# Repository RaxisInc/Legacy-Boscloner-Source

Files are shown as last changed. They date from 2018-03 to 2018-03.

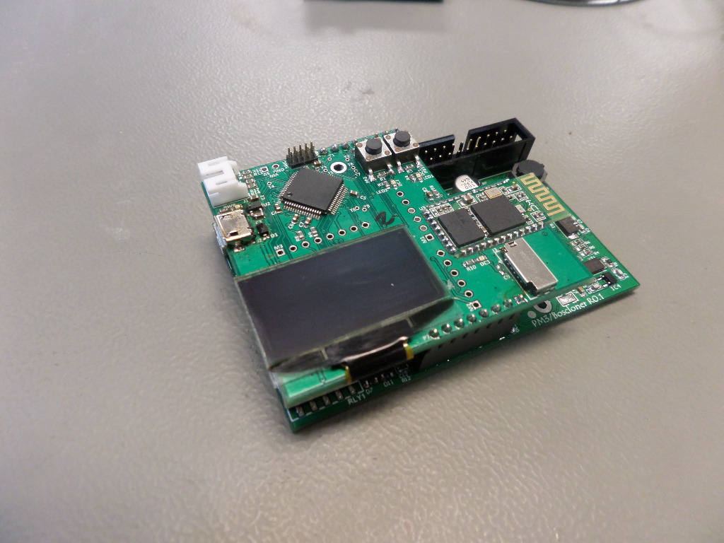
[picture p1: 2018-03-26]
Pics/SAM_0475.JPG

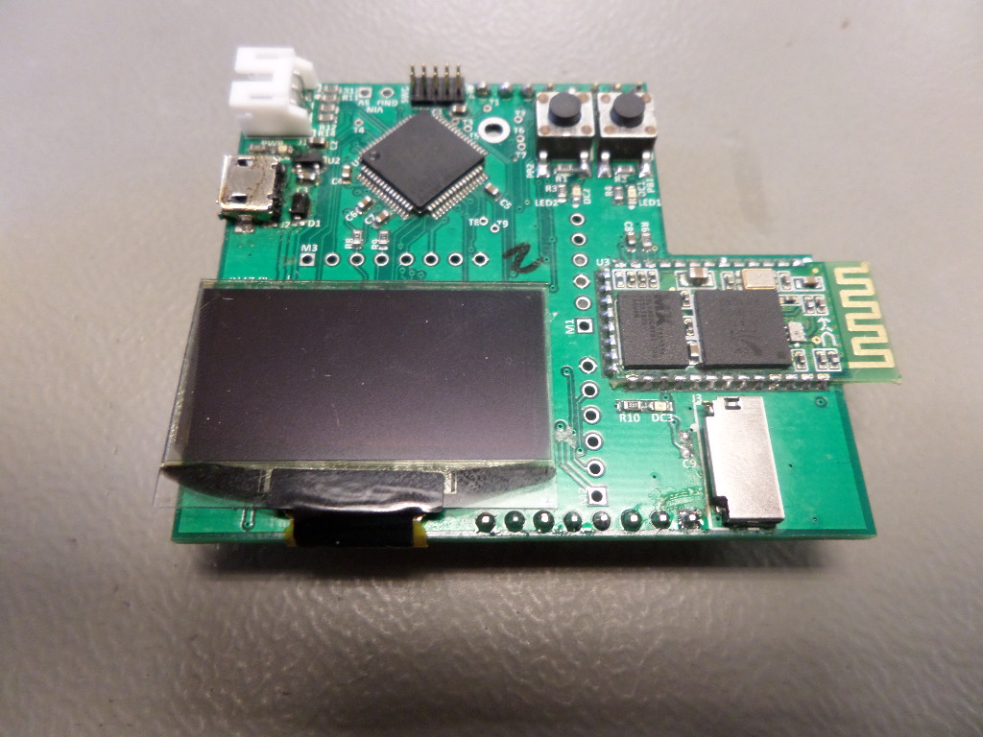
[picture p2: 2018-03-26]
Pics/SAM_0469.JPG

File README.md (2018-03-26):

# Boscloner-Source
The Official Location for All Boscloner Source Files for Hardware, Software, and Apps

In this repository, you'll find all the source, diagrams, BOMs, and more necessary to create your own Boscloner board and shield.

For the Boscloner iOS App Source, visit here:
https://github.com/Boscloner/Boscloner-iOS-App

For the Android App Source, visit here:
https://github.com/Boscloner/Boscloner-Android-App

For assembly, build instructions, and other supporting videos and documentation, visit here:
http://www.boscloner.com

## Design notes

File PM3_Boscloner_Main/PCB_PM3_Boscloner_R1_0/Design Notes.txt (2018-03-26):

Ra.0 errors

- ic9/10 need spaced further based upon replacement part.  Also need to extend pads.

- NCA is nowehow connected where the lcd cs should be.  connected MCU_cs to it!?  But
the correct cs line ps10 is connected to mcu_io3.

PA10 = LCD CS WHICH IS SETUP IN CODE ALREADY.  CAN USE FOR THE PERIPHERAL BOARD.

* routing the SPI pins to shield and secondary processor.

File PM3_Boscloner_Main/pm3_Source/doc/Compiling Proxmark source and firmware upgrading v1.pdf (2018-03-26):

COMPILING PROXMARK SOURCE AND FIRMWARE UPGRADING

Version 1

INTENDED AUDIENCE

The Proxmark III is intended for users that are either competent hardware or software developers (preferably both). Users that do not understand the basic principles behind RFID may have difficulty using the device.

The Proxmark III is a RFID development tool. Typically, an "out of the box" proxmark3 with the latest firmware can run acquisitions in LF and HF mode, output traces, decode a number of different RFID credentials and do some operations in ISO 15693 and ISO 14443 a and b modes. If you really want to get the most out of this device, you will need to start enhancing the firmware yourself to suit your needs.

BEFORE YOU START

This document has been created assuming that you have read the relevant getting started guide and configured your development environment accordingly.

For Windows users – Everything in this document is done from the Minimalist GNU terminal window. Start by running “runme.bat”.

COMPILING PROXMARK SOURCE

Compiling the Proxmark source should be straight forward. To build the project type “make clean && make all”. The clean and build process will only take a few seconds before returning you back to the prompt. If the project was built successfully you should be able to run “./client/proxmark3.exe”. Building the Proxmark project will also produce 3 elf firmware files:

The bootrom image - “./bootrom/obj/bootrom.elf”.

The FPGA image - “./armsrc/obj/fpgaimage.elf”.

The OS image - “./armsrc/obj/osimage.elf”.

If any mention of an error occurs we suggest you request help from the Proxmark community by pasting a copy of the terminal output from the build process and a description of what you were trying to achieve.

FLASHING FIRMWARE

Proxmark firmware is comprised of three logical sections: bootrom, fpga and operating system. The bootrom is a relatively small bit of code that performs some basic hardware initialization, supports reflashing the device over USB and knows how to transfer execution to the operating system. Due to the limited number of features exposed by the bootrom, it is not frequently updated and so you should only rarely need to update it when there is a compatibility conflict.

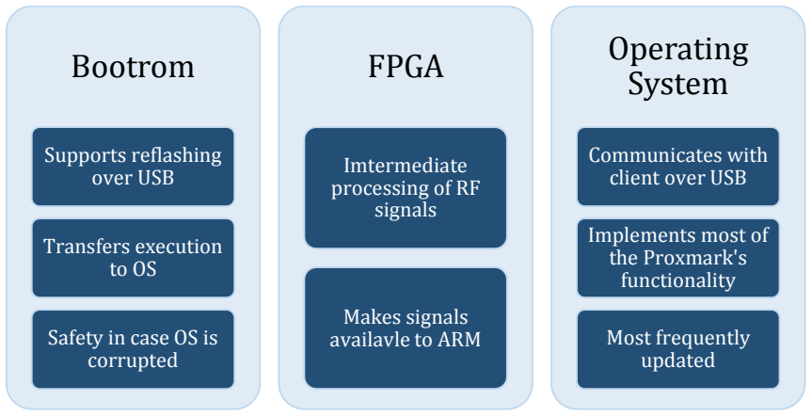
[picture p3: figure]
Bootrom; Supports reflashing over USB; Transfers execution to OS; Safety in case OS is corrupted; FPGA; Imtermediate processing of RF signals; Makes signals availavle to ARM; Operating System; Communicates with client over USB; Implements most of the Proxmark's functionality; Most frequently updated

The FPGA code processes analogue signals coming from the antennas and makes those signals available to the ARM. Like the bootrom code, the FPGA code is not frequently updated. Presently, the operating system is the most frequently updated portion of Proxmark code. It is responsible for receiving and executing most of the commands advertised in the client user interface. Upgrading the bootrom of your Proxmark can brick the device. Please exercise caution when upgrading the bootloader. If the bootloader is corrupted, the only way to restore your Proxmark to working order will be through the use of a JTAG programmer.

FLASHING PROCEDURE

Ensure that you have read the prior section before proceeding. In order to upgrade to the latest version of firmware, you will need to first upgrade the Proxmark’s bootloader.

The steps below will upgrade the Proxmark bootloader to the version you checked out previously using the procedure from the getting started guide.

1. Optional – Update your working copy to the latest revision. (Refer to the getting started documentation).
2. If you have not already done so, open up a terminal and go to the “pm3/client“ directory.
3. Press and hold the button on the Proxmark while connecting it to your computer. Continue to hold the button until the yellow and red LEDs stay lit.
4. Upgrade the Proxmark bootrom by executing the following command:

sudo ./flasher -b ../bootrom/obj/bootrom.elf

At this point the bootrom has been updated and the Proxmark is now in a position to have its OS upgraded. The following steps will upgrade the Proxmark Operating System and FPGA code to your checked revision.

1. Ensure that the Proxmark is not connected to the PC.
2. Hold down the Proxmark’s button and connect it to the PC. After the yellow and red LEDs are lit, execute the command below:

sudo ./flasher ../armsrc/obj/fpgaimage.elf

1. If the previous step is successful, disconnect the Proxmark.
2. While holding the button, connect the Proxmark to the PC and wait for the yellow and red LEDs to stay lit. Execute the command below:

sudo ./flasher ../armsrc/obj/osimage.elf

3. Disconnect the Proxmark from the PC and then reconnect it.
4. Launch the client software by executing “./proxmark3.exe”. The client should successfully connect to the Proxmark. You should see something like this:

Connected units:

1. SN: ChangeMe [bus-0/\\.\libusb0-0001--0x9ac4-0x4b8f]

proxmark3>

JTAG RECOVERY PROCEDURE

If for whatever reason the USB upgrade procedure (section above) failed and the Proxmark will no longer boot, you will need to load the bootrom on to the Proxmark using the JTAG interface. This procedure assumes that you have a Segger J-LINK for the recovery process and J-Flash ARM installed on a PC running Windows 7.

1. Plug the Proxmark and the Segger J-LINK in to the computer.
2. Attach the J-LINK to the Proxmark JTAG port.
3. Open J-Flash ARM.
4. Create a new project by selecting File > New project.
5. Change the project settings by going to Options > Project settings…

– or –

Alt | + | F7 .
6. Click on the Target Interface tab.
7. Change the JTAG speed before init to 200 kHz.
8. Click on the CPU tab.
9. Select the Device radio button and select Atmel AT91SAM7S256 from the drop down list.
10. Change the Clock speed to Auto detection.
11. Apply and OK the changes.
12. Test connectivity to the Proxmark by selecting Target > Connect.

13. Disconnect from the Proxmark by selecting Target > Disconnect.
14. Open the data file by selecting File > Open data file…

– or –

Ctrl | + | O .
15. Open the file “bootrom.s19” which should be located in the “pm3\bootrom\obj” folder. If it is not there, you will need to re-build the project.
16. Program the Proxmark and verify the process by selecting Target > Program & Verify

– or –

F6 .

17. You should expect to see an error saying that the program does not fit into the selected flash sectors. Select Yes to relocate and continue.
18. Disconnect from the Proxmark by selecting Target > Disconnect.
19. Exit J-Flash ARM.
20. Remove the J-LINK from the Proxmark.
21. Wait a little while and the Proxmark should automatically re-start. You can always un-plug and re-plug the Proxmark if you wish. You can then attempt to re-connect to the Proxmark using the client software.

Thanks to the proxmark3.com guys for letting me use some of their original content!

USEFUL LINKS

The Proxmark forum | http://proxmark.org/forum/index.php
Proxmark III online store | http://proxmark3.com/
Proxmark project downloads | http://code.google.com/p/proxmark3/downloads/list
The Proxmark project | http://code.google.com/p/proxmark3/
The Proxmark wiki | http://code.google.com/p/proxmark3/wiki/HomePage?tm=6
Proxmark repository | http://proxmark3.googlecode.com/svn/trunk/
Document corrections or comments | http://proxmark.org/forum/viewforum.php?id=27

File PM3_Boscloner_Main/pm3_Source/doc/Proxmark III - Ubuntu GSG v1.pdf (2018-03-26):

GETTING STARTED GUIDE FOR UBUNTU (GNOME) USERS

Version 1

INTENDED AUDIENCE

The Proxmark III is intended for users that are either competent hardware or software developers (preferably both). Users that do not understand the basic principles behind RFID may have difficulty using the device.

The Proxmark III is a RFID development tool. Typically, an "out of the box" proxmark3 with the latest firmware can run acquisitions in LF and HF mode, output traces, decode a number of different RFID credentials and do some operations in ISO 15693 and ISO 14443 a and b modes. If you really want to get the most out of this device, you will need to start enhancing the firmware yourself to suit your needs.

INTRODUCTION

The proxmark3 is a powerful general purpose RFID tool, the size of a deck of cards, designed to snoop, listen and emulate everything from Low Frequency (125 kHz) to High Frequency (13.56 MHz) tags.

This device can do almost anything involving almost any kind of low (125 kHz) or high (13.56 MHz) frequency RFID tag. It can act as a reader. It can eavesdrop on a transaction between another reader and a tag. It can analyse the signal received over the air more closely, for example to perform an attack in which we derive information from the tag’s instantaneous power consumption. It can pretend to be a tag itself. It is also capable of some less obviously useful operations that might come in handy for development work.

HISTORY

“The Proxmark III is a device developed by Jonathan Westhues that enables sniffing, reading and cloning of RFID (Radio Frequency Identification) tags. For my master thesis I wanted to look at the communication of Mifare Classic cards. Mifare Classic is used in many applications and is the most popular contactless card around. It is used in e-ticketing, public transport and access control. The higher-level protocol is kept secret by the manufacturer (NXP). I made an implementation of the ISO14443 type A standard for the Proxmark since Mifare is based on this communication standard.

After a lot of debugging and many noisy traces the Proxmark was ready for some real analysis. I focused on the Mifare Classic card and was happy to let the communication between card and reader appear on my screen. I could see the anticollision phase where the reader selects the card to communicate with. This was followed by an authentication and after that all communication was encrypted. The findings of this research are published on arxiv.org as A Practical Attack on the Mifare Classic

In December 2007 I saw the presentation of Karsten Nohl and Henryk Plotz where they showed how they reverse engineered the Mifare Classic chip. I was working on the same subject in Nijmegen. The Mifare system relied on security by obscurity and now the secrets are revealed there is no card-level security left. A video on YouTube shows a demo that we gave on March 12th. It shows how we access a building with a cloned card.

We will not release the software used in the MIFARE Classic attacks.

Gerhard de Koning Gans, Roel Verdult”

HARDWARE OVERVIEW

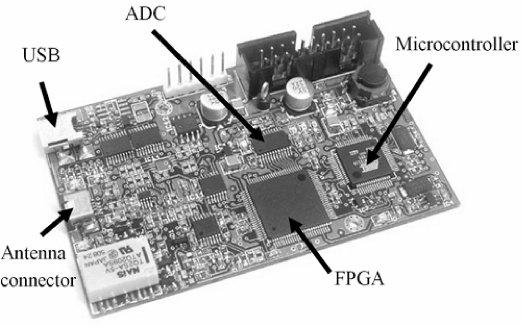
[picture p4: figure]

ADC (ANALOG TO DIGITAL CONVERTER)

The analogue signal that comes from the antenna circuit is fed into an 8-bit Analogue to Digital Converter (ADC). This delivers 8 output bits in parallel which represent the current voltage retrieved from the field.

FIELD PROGRAMMABLE GATE ARRAY

The 8 output pins from the ADC are connected to 8 pins of the Field Programmable Gate Array (FPGA). An FPGA has a great advantage over a normal microcontroller in the sense that it emulates hardware. A hardware description can be compiled and flashed into an FPGA.

Because basic arithmetic functions can be performed fast and in parallel by an FPGA it is faster than an implementation on a normal microcontroller. Only a real hardware implementation would be faster but this lacks the flexibility of an FPGA.

The FPGA can therefore be seen as dynamic hardware. It is possible to make a hardware design and flash it into the memory of the FPGA. This gives some major advantages:

"Hardware" errors can be corrected; the FPGA can be flashed with a new hardware design. Although not as fast as a real hardware implementation, an FPGA is faster than its equivalent on a microprocessor. That is, it is specialized for one job.

The FPGA has two main tasks. The first task is to demodulate the signal received from the ADC and relay this as a digital encoded signal to the ARM. Depending on the task this might be the demodulation of a

100% Amplitude Shift Keying (ASK) signal from the reader or the load modulation of a card. The encoding schemes used to communicate the signal to the ARM are Modified Miller for the reader and Manchester encoding for the card signal.

The second task is to modulate an encoded signal that is received from the ARM into the field of the antenna. This can be both the encoding of reader messages or card messages. For reader messages the FPGA generates an electromagnetic field on power hi and drops the amplitude for short periods.

MICROCONTROLLER

The microcontroller is responsible for the protocol management. It receives the digital encoded signals from the FPGA and decodes them. The decoded signals can just be copied to a buffer in the EEPROM memory. Additionally, an answer to the received message can be send by encoding a reply and communicating this to the FPGA.

The microcontroller (ARM) implements the transport layer. First it decodes the samples received from the FPGA. These samples are stored in a Direct Memory Access (DMA) buffer. The samples are binary sequences that represent whether the signal was high or low. The software on the ARM tries to decode these samples. When the Proxmark is in sniffing mode this is done for both the Manchester and Modified Miller at the same time. Whenever one of the decoding procedures returns a valid message, this message is stored in another buffer (BigBuf) and both decoding procedures are set to an un-synced state. The BigBuf is limited to the available memory on the ARM. The current firmware has 2 KB of memory reserved for traces (Besides the traces the buffer also stores some temporary data that is needed in the processing). When the BigBuf buffer is full the function normally returns. A new function call from the client is needed to download the BigBuf contents to the computer. The BigBuf is especially useful for protocol investigation. Every single message is stored in this buffer. When a card is emulated or when the Proxmark is used as a reader the BigBuf can be used to store status messages or protocol exceptions.

USB

The USB interface interconnects the Proxmark with an external power supply and / or a computer for advanced functionality.

ANTENNA CONNECTOR

The antenna connector is a Hirose Electric low profile, surface mount, right-angle 4 pin connector. This connector allows for the simultaneous connection of a low and high frequency antenna.

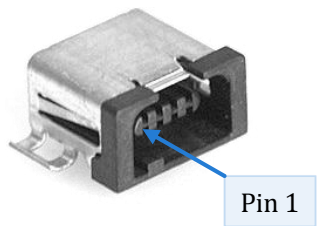
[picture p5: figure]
Pin 1

The low frequency antenna (125/134 kHz) connects to Pin 1 (TP5) and Pin 2 (TP2). The high frequency antenna (13.56MHz) connects to Pin 3 (TP4) and Pin 4 (TP3).

GETTING STARTED

It is assumed that the reader of this document is running Ubuntu 11.10. This document is intended as a guide only. Group policies and custom configurations are outside the scope of this document.

A high and low frequency antenna will be required when testing the Proxmark. The antenna construction is outside the scope of this document. It is assumed that the antennas have been assembled and tested prior to reading “Testing the Proxmark”.

REQUIREMENTS

A computer running Ubuntu 11.10 with an available USB port.
- This guide will most likely work with:
- Ubuntu 11.04, 10.10 and 10.04.
- BackTrack 5 R1 and 4 R2.
A USB Mini-B lead.
A Proxmark III.
HF and / or LF antenna for the Proxmark.

A technical understanding of the Proxmark III is not required for the installation process.

DEVELOPMENT ENVIRONMENT INSTALLATION

1. Open a terminal: | CTRL | + | ALT | + | T | .
2. Download (and install) TortoiseSVN, p7zip, and components essential to build the Proxmark from
soruce: “sudo apt-get install subversion p7zip build-essential libreadline5

libreadline-dev libusb-0.1-4 libusb-dev libqt4-dev perl pkg-config wget”.
3. Check out the latest revision of the Proxmark project: “svn checkout

http://proxmark3.googlecode.com/svn/trunk pm3”.
4. Get devkitARM release 32 (4.5.1) from SourceForge: http://sourceforge.net/projects/devkitpro/files/devkitARM/previous/devkitARM_r32-i686-linux.tar.bz2/download (http://sourceforge.net/projects/devkitpro/files/devkitARM/previous/devkitARM_r32-i686-linux.tar.bz2/download)
5. Extract the contents of the .tar.bz2: “tar jxvf devkitARM_r32-i686-linux.tar.bz2”.
6. Create a directory for the arm dev kit: “sudo mkdir /opt/devkitpro/”.
7. Move the ARM developer kit to the newly created directory: “sudo mv devkitARM

/opt/devkitpro/”.
8. Add the appropriate environment variable: “export

PATH=${PATH}:/opt/devkitpro/devkitARM/bin/”.
9. Add the environment variable to your profile: “echo

'PATH=${PATH}:/opt/devkitpro/devkitARM/bin/' >> ~/.bashrc”.

PROXMARK DRIVER INSTALLATION

No drivers are required to use the Proxmark within Linux. You will however need to run the client as root.

TESTING THE PROXMARK

You are now at the stage where you should be able to communicate with your Proxmark.

1. Go in to your Proxmark project folder and run the Proxmark software – “sudo

./client/proxmark3.exe”.
1.1. You should see something like this:

Connected units:

1. SN: ChangeMe [bus-0/\\.\libusb0-0001--0x9ac4-0x4b8f]

proxmark3>

2. Next, check what firmware you are running – “hw version”.
2.1. You should see something like this:

#db# Prox/RFID mark3 RFID instrument

#db# bootrom: svn 486-suspect 2011-07-18 12:48:52

#db# os: svn 486-suspect 2011-07-18 12:48:57

#db# FPGA image built on 2009/12/ 8 at 8: 3:54

3. Connect your antenna(s) to the Proxmark and type in “hw tune”.
3.1. You should see something like this:

#db# Measuring antenna characteristics, please wait.

# LF antenna: 33.17 V @ | 125.00 kHz

# LF antenna: 41.89 V @ | 134.00 kHz

# LF optimal: 41.76 V @ | 127.66 kHz

# HF antenna: | 7.28 V @ | 13.56 MHz

4. Type “quit” to exit out of the program.

NOTES

There are many commands available within the Proxmark client. Type “help” to list the commands available to you. You get a list of following subcommands by typing in the command you’re interested followed by help (Eg. “hf help”). For detailed help please read the Proxmark User Manual.

Command shortcutting is permitted. For instance typing “hf mf re” will achieve the same results as typing “hf mf restore1k” because it is the only “hf mf” command available that begins with “re”.

You might have noticed when you executed the command “hw version” there was a “-unclean” or “-suspect” in the “bootrom” or “os” version information. This information indicates that the code may have changes in the local code versus the subversion revision.

A clean build is a build that has no local changes versus the subversion revision.
Unclean builds have local changes versus the subversion revision.
Suspect builds cannot be compared against the subversion revision.

NEXT STEPS

From here on in the rest is up to you. You might want to confirm that the firmware you’re running is the latest. In addition to this you might want to begin reading through the Proxmark source code and making changes of your own.

We suggest you read the following documentation:

Compiling Proxmark source and firmware upgrading Proxmark User Manual
Antenna Construction Guide

THE FORUM

We hope you thoroughly enjoy using the Proxmark and encourage you to join the forum and introduce yourself - http://proxmark.org/forum/index.php. There are a number of active members willing to assist newcomers. Please note the forum is not a help desk for inexperienced developers. Poor English,

USEFUL LINKS

The Proxmark forum | http://proxmark.org/forum/index.php
Proxmark project downloads | http://code.google.com/p/proxmark3/downloads/list
The Proxmark project | http://code.google.com/p/proxmark3/
The Proxmark wiki | http://code.google.com/p/proxmark3/wiki/HomePage?tm=6
Proxmark repository | http://proxmark3.googlecode.com/svn/trunk/
7-Zip | http://www.7-zip.org
Tortoise SVN | http://tortoisesvn.net
Document corrections or comments | http://proxmark.org/forum/viewforum.php?id=27

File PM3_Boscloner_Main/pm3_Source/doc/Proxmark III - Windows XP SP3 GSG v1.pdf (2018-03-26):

# PROXMARK III

GETTING STARTED GUIDE FOR WINDOWS XP USERS

Version 1

INTENDED AUDIENCE

The Proxmark III is intended for users that are either competent hardware or software developers (preferably both). Users that do not understand the basic principles behind RFID may have difficulty using the device.

The Proxmark III is a RFID development tool. Typically, an "out of the box" proxmark3 with the latest firmware can run acquisitions in LF and HF mode, output traces, decode a number of different RFID credentials and do some operations in ISO 15693 and ISO 14443 a and b modes. If you really want to get the most out of this device, you will need to start enhancing the firmware yourself to suit your needs.

INTRODUCTION

The proxmark3 is a powerful general purpose RFID tool, the size of a deck of cards, designed to snoop, listen and emulate everything from Low Frequency (125 kHz) to High Frequency (13.56 MHz) tags.

This device can do almost anything involving almost any kind of low (125 kHz) or high (13.56 MHz) frequency RFID tag. It can act as a reader. It can eavesdrop on a transaction between another reader and a tag. It can analyse the signal received over the air more closely, for example to perform an attack in which we derive information from the tag’s instantaneous power consumption. It can pretend to be a tag itself. It is also capable of some less obviously useful operations that might come in handy for development work.

HISTORY

“The Proxmark III is a device developed by Jonathan Westhues that enables sniffing, reading and cloning of RFID (Radio Frequency Identification) tags. For my master thesis I wanted to look at the communication of Mifare Classic cards. Mifare Classic is used in many applications and is the most popular contactless card around. It is used in e-ticketing, public transport and access control. The higher-level protocol is kept secret by the manufacturer (NXP). I made an implementation of the ISO14443 type A standard for the Proxmark since Mifare is based on this communication standard.

After a lot of debugging and many noisy traces the Proxmark was ready for some real analysis. I focused on the Mifare Classic card and was happy to let the communication between card and reader appear on my screen. I could see the anticollision phase where the reader selects the card to communicate with. This was followed by an authentication and after that all communication was encrypted. The findings of this research are published on arxiv.org as A Practical Attack on the Mifare Classic

In December 2007 I saw the presentation of Karsten Nohl and Henryk Plotz where they showed how they reverse engineered the Mifare Classic chip. I was working on the same subject in Nijmegen. The Mifare system relied on security by obscurity and now the secrets are revealed there is no card-level security left. A video on YouTube shows a demo that we gave on March 12th. It shows how we access a building with a cloned card.

We will not release the software used in the MIFARE Classic attacks.

Gerhard de Koning Gans, Roel Verdult”

HARDWARE OVERVIEW

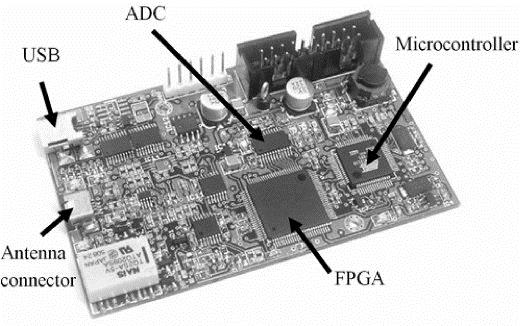
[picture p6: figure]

ADC (ANALOG TO DIGITAL CONVERTER)

The analogue signal that comes from the antenna circuit is fed into an 8-bit Analogue to Digital Converter (ADC). This delivers 8 output bits in parallel which represent the current voltage retrieved from the field.

FIELD PROGRAMMABLE GATE ARRAY

The 8 output pins from the ADC are connected to 8 pins of the Field Programmable Gate Array (FPGA). An FPGA has a great advantage over a normal microcontroller in the sense that it emulates hardware. A hardware description can be compiled and flashed into an FPGA.

Because basic arithmetic functions can be performed fast and in parallel by an FPGA it is faster than an implementation on a normal microcontroller. Only a real hardware implementation would be faster but this lacks the flexibility of an FPGA.

The FPGA can therefore be seen as dynamic hardware. It is possible to make a hardware design and flash it into the memory of the FPGA. This gives some major advantages:

- "Hardware" errors can be corrected; the FPGA can be flashed with a new hardware design.
- Although not as fast as a real hardware implementation, an FPGA is faster than its equivalent on a microprocessor. That is, it is specialized for one job.

The FPGA has two main tasks. The first task is to demodulate the signal received from the ADC and relay this as a digital encoded signal to the ARM. Depending on the task this might be the demodulation of a

100% Amplitude Shift Keying (ASK) signal from the reader or the load modulation of a card. The encoding schemes used to communicate the signal to the ARM are Modified Miller for the reader and Manchester encoding for the card signal.

The second task is to modulate an encoded signal that is received from the ARM into the field of the antenna. This can be both the encoding of reader messages or card messages. For reader messages the FPGA generates an electromagnetic field on power hi and drops the amplitude for short periods.

MICROCONTROLLER

The microcontroller is responsible for the protocol management. It receives the digital encoded signals from the FPGA and decodes them. The decoded signals can just be copied to a buffer in the EEPROM memory. Additionally, an answer to the received message can be send by encoding a reply and communicating this to the FPGA.

The microcontroller (ARM) implements the transport layer. First it decodes the samples received from the FPGA. These samples are stored in a Direct Memory Access (DMA) buffer. The samples are binary sequences that represent whether the signal was high or low. The software on the ARM tries to decode these samples. When the Proxmark is in sniffing mode this is done for both the Manchester and Modified Miller at the same time. Whenever one of the decoding procedures returns a valid message, this message is stored in another buffer (BigBuf) and both decoding procedures are set to an un-synced state. The BigBuf is limited to the available memory on the ARM. The current firmware has 2 KB of memory reserved for traces (Besides the traces the buffer also stores some temporary data that is needed in the processing). When the BigBuf buffer is full the function normally returns. A new function call from the client is needed to download the BigBuf contents to the computer. The BigBuf is especially useful for protocol investigation. Every single message is stored in this buffer. When a card is emulated or when the Proxmark is used as a reader the BigBuf can be used to store status messages or protocol exceptions.

USB

The USB interface interconnects the Proxmark with an external power supply and / or a computer for advanced functionality.

ANTENNA CONNECTOR

The antenna connector is a Hirose Electric low profile, surface mount, right-angle 4 pin connector. This connector allows for the simultaneous connection of a low and high frequency antenna.

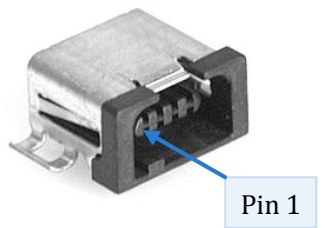
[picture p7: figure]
Pin 1

- The low frequency antenna (125/134 kHz) connects to Pin 1 (TP5) and Pin 2 (TP2).
- The high frequency antenna (13.56MHz) connects to Pin 3 (TP4) and Pin 4 (TP3).

GETTING STARTED

It is assumed that the reader of this document is the local administrator of a machine running Windows XP Professional SP3. This document is intended as a guide only. Group policies and custom configurations are outside the scope of this document.

A high and low frequency antenna will be required when testing the Proxmark. The antenna construction is outside the scope of this document. It is assumed that the antennas have been assembled and tested prior to reading “Testing the Proxmark”.

REQUIREMENTS

- A computer running Windows XP Professional SP3 with an available USB port.
- A USB Mini-B lead.
- A Proxmark III.
- HF and / or LF antenna for the Proxmark.

A technical understanding of the Proxmark III is not required for the installation process.

DEVELOPMENT ENVIRONMENT INSTALLATION

1. Download (and install) 7-ZIP from here: http://www.7-zip.org/download.html
2. Download (and install) TortoiseSVN from here: http://tortoisesvn.net/downloads.html
3. Download “ProxSpace-20100226-r390.7z” from:
http://code.google.com/p/proxmark3/downloads/list
4. “ProxSpace-20100226-r390.7z” should be extracted wherever you want to keep the Proxmark project. Additionally, the location should not include spaces. For instance –
“C:\Projects\Proxmark” would be acceptable whereas “C:\Documents and

Settings\Administrator\My Projects\Proxmark” would not.
5. Assuming you installed 7-ZIP using all of the default options, you should have 7-ZIP context menu items.
6. Right-click “ProxSpace-20100226-r390.7z” and select 7-Zip > Extract Here.
7. Assuming you installed TortoiseSVN using all of the default options, you should have subversion context menu items.
8. Go in to the newly created ProxSpace folder and right-click the “pm3” folder. Select SVN Update.
9. In the ProxSpace folder there should be a file called “runme.bat”. Open this file with a suitable text editor. (N++ is recommended)
9.1. You will need to modify the variable "MYPATH".

EXAMPLE

If your ProxSpace folder path is “C:\ProxMark\ProxSpace” you would need to change the

“MYPATH” variable to “set MYPATH=%~d0\ProxMark\ProxSpace”.

9.2. The last line of the batch file might have a forward slash – “msys/msys.bat”. You will need to change this to “msys\msys.bat ”.
9.3. Save and close the file.

10. Test the configuration by running “runme.bat”. You should see a Minimalist GNU terminal window.
11. Type “exit” to close the window.

PROXMARK DRIVER INSTALLATION

1. Download the Proxmark drivers (“ProxSpace-Driver-Current.7z”) from here: http://code.google.com/p/proxmark3/downloads/list
2. Assuming you installed 7-ZIP using all of the default options (Development Environment Installation
Step 1.), you should have 7-ZIP context menu items.
3. Right-click “Proxmark-Driver.7z” and select 7-Zip > Extract Here.
4. Attach the Proxmark to the computer. A notification in the tray should appear indicating the ProxMark has been detected.
5. Open the Device Manager.

Start > Control Panel > System > Hardware > Device Manager.

– or –

Win | + | Pause / Break | > Hardware > Device Manager.
6. Expand out the “Human Interface Devices” and double-click the last “USB Human Interface Device” in the tree.
7. In the window that appears, verify the device selected is the Proxmark by checking the “Location” field.
7.1. If the “Location field” does not contain “ProxMark-3 RFID Instrument”, close the window and try another “USB Human Interface Device” in the tree.
8. Click Driver > Update Driver… > No, not this time > Next > Install from a list or specific location (Advanced) > Next > Don't search. I will choose the driver to install. > Next > Have Disk… > Browse….
9. In the Locate File window, navigate to the Proxmark Driver folder created at step 3. Select “ProxMark-3_RFID_Instrument.inf” then click Open > Ok > Next > Finish.
9.1. If you go back in to the Device Manager you should see “ProxMark-3 RFID Instrument” under the “LibUSB-Win32 Devices” node.

TESTING THE PROXMARK

You are now at the stage where you should be able to communicate with your Proxmark.

1. Go in to your Proxmark project folder and run the “runme.bat” file.
1.1. If for whatever reason “runme.bat” does not open a Minimalist GNU terminal window, open a command prompt and run “runme.bat” from there. By doing so you should see any errors and diagnose the problem.

2. Run the Proxmark software – “./client/proxmark3.exe”.
2.1. You should see something like this:

Connected units:

1. SN: ChangeMe [bus-0/\\.\libusb0-0001--0x9ac4-0x4b8f]

proxmark3>

3. Next, check what firmware you are running – “hw version”.
3.1. You should see something like this:

#db# Prox/RFID mark3 RFID instrument

#db# bootrom: svn 486-suspect 2011-07-18 12:48:52

#db# os: svn 486-suspect 2011-07-18 12:48:57

#db# FPGA image built on 2009/12/ 8 at 8: 3:54

4. Connect your antenna(s) to the Proxmark and type in “hw tune”.
4.1. You should see something like this:

#db# Measuring antenna characteristics, please wait.

# LF antenna: 33.17 V @ | 125.00 kHz

# LF antenna: 41.89 V @ | 134.00 kHz

# LF optimal: 41.76 V @ | 127.66 kHz

# HF antenna: | 7.28 V @ | 13.56 MHz

5. Type “quit” to exit out of the program.

NOTES

There are many commands available within the Proxmark client. Type “help” to list the commands available to you. You get a list of following subcommands by typing in the command you’re interested followed by help (Eg. “hf help”). For detailed help please read the Proxmark User Manual.

Command shortcutting is permitted. For instance typing “hf mf re” will achieve the same results as typing “hf mf restore1k” because it is the only “hf mf” command available that begins with “re”.

You might have noticed when you executed the command “hw version” there was a “-unclean” or “-suspect” in the “bootrom” or “os” version information. This information indicates that the code may have changes in the local code versus the subversion revision.

- A clean build is a build that has no local changes versus the subversion revision.
- Unclean builds have local changes versus the subversion revision.
- Suspect builds cannot be compared against the subversion revision.

NEXT STEPS

From here on in the rest is up to you. You might want to confirm that the firmware you’re running is the latest. In addition to this you might want to begin reading through the Proxmark source code and making changes of your own.

We suggest you read the following documentation:

- Compiling Proxmark source and firmware upgrading
- Proxmark User Manual
- Antenna Construction Guide

THE FORUM

We hope you thoroughly enjoy using the Proxmark and encourage you to join the forum and introduce yourself - http://proxmark.org/forum/index.php. There are a number of active members willing to assist newcomers. Please note the forum is not a help desk for inexperienced developers.

USEFUL LINKS

The Proxmark forum | http://proxmark.org/forum/index.php
Proxmark project downloads | http://code.google.com/p/proxmark3/downloads/list
The Proxmark project | http://code.google.com/p/proxmark3/
The Proxmark wiki | http://code.google.com/p/proxmark3/wiki/HomePage?tm=6
Proxmark repository | http://proxmark3.googlecode.com/svn/trunk/
7-Zip | http://www.7-zip.org
Tortoise SVN | http://tortoisesvn.net
Document corrections or comments | http://proxmark.org/forum/viewforum.php?id=27

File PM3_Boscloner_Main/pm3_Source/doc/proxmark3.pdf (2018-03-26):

# Working with RFID Tags— An Introduction to the proxmark3

Jonathan Westhues

user jwesthues, at host cq.cx

## 1 Overview

I intend this document as a brief introduction to my proxmark3 hardware. In addition to this, I will try to describe the signal processing that this device must perform. In concept this is the same correlation that any digital radio receiver performs; some details are fundamentally specific to the kinds of signals involved in an RFID system, and some are specific to my implementation.
The proxmark3 is a test instrument capable of manipulating RFID tags in a number of different ways. For example, a proxmark3 can:

read almost any low-frequency (∼100 kHz) or high-frequency (13.56 MHz) tag, including the ISO-standard tags;

emulate a low- or high-frequency tag, appearing almost indistinguishable from a real tag; or

eavesdrop on the signals exchanged between another reader and tag

When the reader wants to receive a signal from the tag (whether we are reading an ID-only tag, like a prox card, or whether we are expecting some response that is a function of some message that we previously sent to a 13.56 MHz ISO-standard tag), it transmits only the unmodulated carrier that powers the tag. The tag transmits its message by alternately making the circuit across its antenna look more like an open, or more like a short (or, equivalently, by changing the resonant frequency of its antenna circuit, by disconnecting or reconnecting some inductance or capacitance to the antenna; the reader ‘sees the tag more’ when the tag’s antenna resonates closer to the frequency of the energizing carrier).
The reader sees a lower voltage at its antenna when the tag’s antenna is ‘more shorted.’ This means that the tag can amplitude-modulate a subcarrier onto the carrier transmitted by the reader, by varying the
It looks at the received signal on its antenna—possibly, but not necessarily, the same antenna used to transmit—and demodulates this signal

1

In a sense, the circuit that interprets the signal returned from the tag is a radio receiver like any other. The major peculiarity in this application is that our transmitted carrier will always bleed through, because it is so much more powerful than the information-bearing signal returned from the tag. We can consider the signal at the reader’s antenna as having the form

v(t) = (Ac + vs(t))(cos ωct) = Ac cos ωct + vs(t) cos ωct = vtx(t) + vrx(t)

where Ac is the amplitude of the transmitted carrier, ωc is the carrier frequency (125 kHz or 13.56 MHz), and vr(t) is the subcarrier amplitude-modulated onto the transmitted carrier by the tag. Only the signal vr(t) carries information; the Ac cos ωct term serves only to power the tag, but it still appears at our antenna. The subcarrier frequencies used in typical RFID standards are small compared to the carrier frequency.¹ This means that the vs(t) cos ωct term is a relatively narrow bandpass signal centred at ωc.
Unfortunately, the Ac cos ωct term is much more powerful than vrx. This must be so; only a fraction of the power that the reader transmits will make it to the tag, and only a fraction of the power the tag reflects back towards the reader will be receiverd by the reader’s antenna. In radio terms, this means that we will always have to deal with a powerful in-band interferer. Our receiver must therefore have very high dynamic range. This is difficult for a software radio, because the resolution of the A/D fundamentally limits the radio’s dynamic range.
This problem starts at the antenna. If a single antenna is used for both receive and transmit, then there is nothing to be done—we will always see the full transmit strength of the carrier that powers the tag.²
It is possible to use two
antennae, one for receive and one for transmit, and attempt to design these so that the receive antenna gets as little of the transmitted carrier as possible. At UHF or microwave frequencies, this is a particularly useful technique, because it is practical to construct a directional antenna. A similar approach can be taken at HF or LF: consider what happens if you have separate receive and transmit coils, at ninety degrees to each other (with the tag at 45 degrees to both of them).
Given a particular choice of antenna, this problem may now be addressed by analog signal processing in front of the A/D. Considering the problem in the frequency domain, it is obvious that what is needed is a tight notch filter at the carrier frequency—the vtx(t) = Ac cos ωct has energy at only one frequency, and we know that frequency exactly, because we are the ones (at the reader) generating it. As long the signal vrx(t) has no energy very close to ωc (or as long as we can still demodulate vrx(t) after losing any components close to ωc), the notch filter will not affect our information-bearing signal.³

1With some exceptions; for example, Motorola/Indala’s FlexPass cards do BPSK on a 62.5 kHz subcarrier, with a 125 kHz carrier. I don’t know of any 13.56 MHz standards that use wide modulation, though.
2Unless we try an isolator or other non-reciprocal device.
3And if vrx(t) did have important components near ωc, then the situation would be hope-

2

(a) A ceramic or crystal filter is one practical implementation of this. The filter could either be applied directly, at the carrier frequency, or at at some IF after mixing the signal up or down. The frequency tolerance is tight enough that passive RLC, switched-capacitor, or active (R, C, and opamp) filters are not practical; but if the received signal is (b) mixed down by the carrier frequency, then the carrier is translated to DC, and the notch filter becomes a low-pass, which might be easier to implement. At that point only the dynamic range of the mixer is an issue, and that is likely an easier problem to solve.
(c) Equivalently, we could try to measure Ac, and add in

−Ac cos ωct

to try to cancel out the
Ac cos ωct

Even if we didn’t do a perfect job, we would still be able to reduce the amplitude of the carrier term considerably, and perhaps reduce the dynamic range of the signal to the point that it was practical to handle it digitally from there on.
(d) Considering the problem in the time domain, the signal returned from the tag is an information-bearing subcarrier that amplitude-modulates the carrier. We wish to measure the amplitude of the received signal, which gives us

va(t) = Ac + vs(t)

This is the subcarrier (that we want), plus a DC offset corresponding to the amplitude of the bled-through carrier. We can high-pass filter va(t) with a very slow time constant to reject the DC offset, leaving only the subcarrier. It is necessary that vs(t) not carry any important information near DC, because those frequency components are rejected by the high-pass filter. This is equivalent to the previous requirement that vrx(t) not carry any important information near ωc.
This device uses a single antenna for both receive and transmit, followed by a peak detector and simple analog filters. No frequency-domain attempt is made to reject our transmitted carrier. Since this device is intended as a test instrument, and not a long-range reader where the receiver sensitivity is critical, I consider this to be acceptable, but much better RF performance in the presence of noise (and our own transmitted carrier) could be achieved.

less, because Ac depends on a number of factors, including things like the proximity of metal objects to the reader.

3

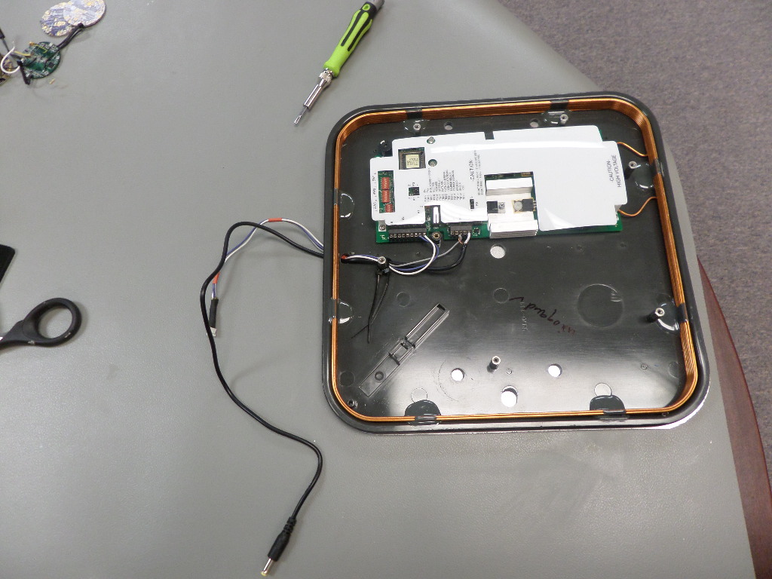
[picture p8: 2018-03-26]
Pics/SAM_0460.JPG

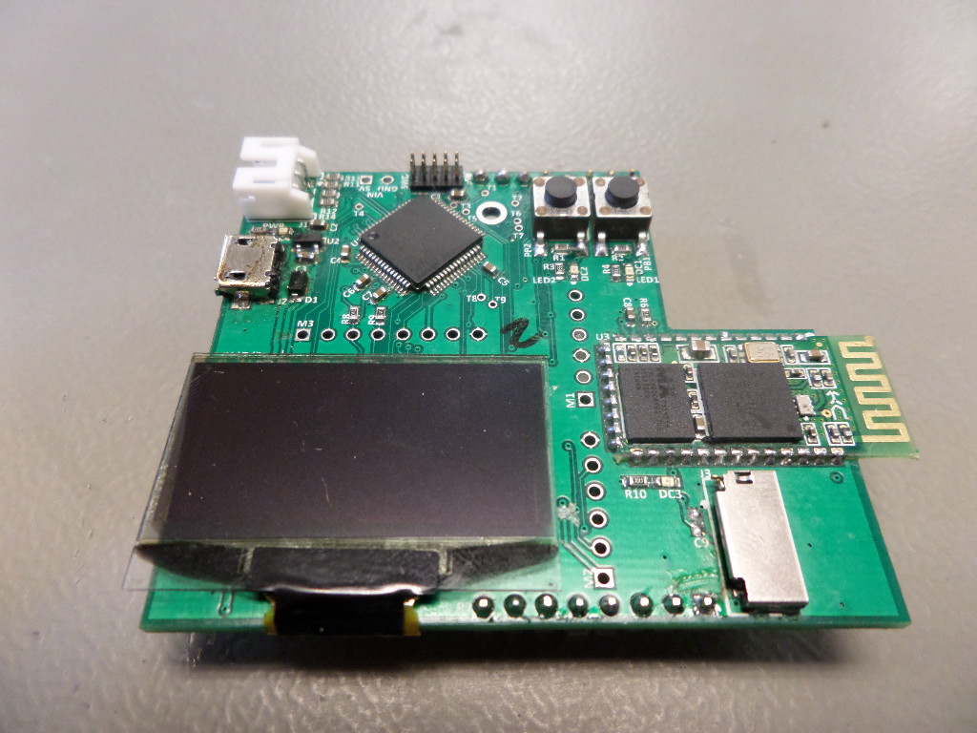
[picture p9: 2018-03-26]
Pics/SAM_0470.JPG

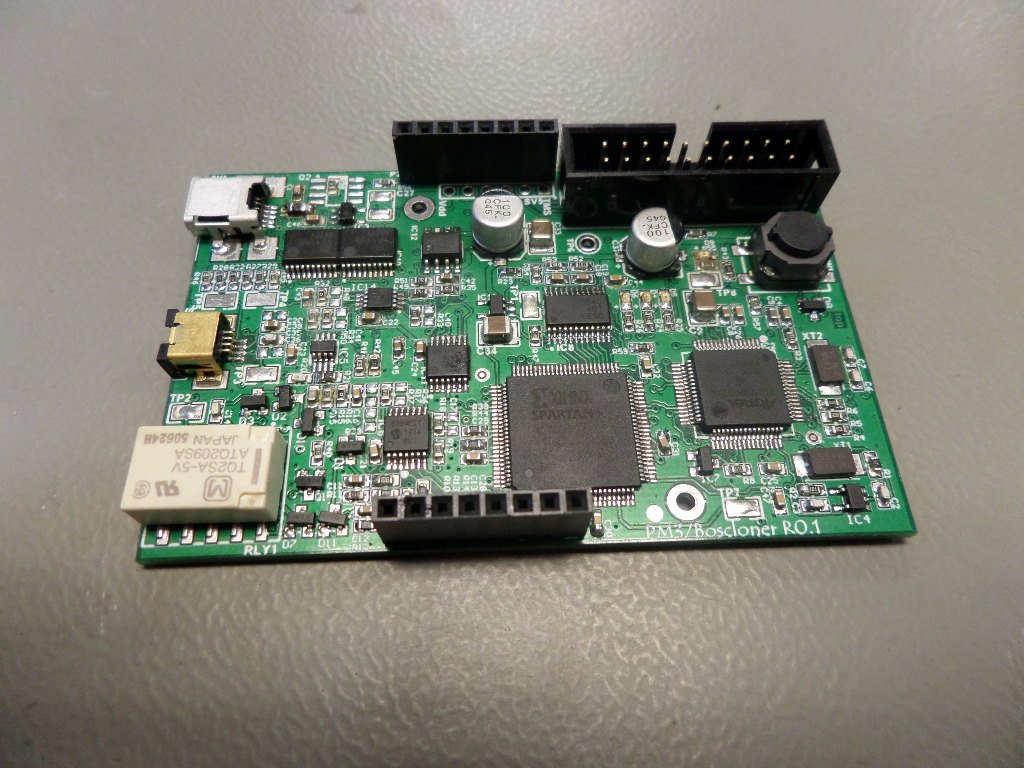
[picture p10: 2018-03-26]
Pics/SAM_0468.JPG

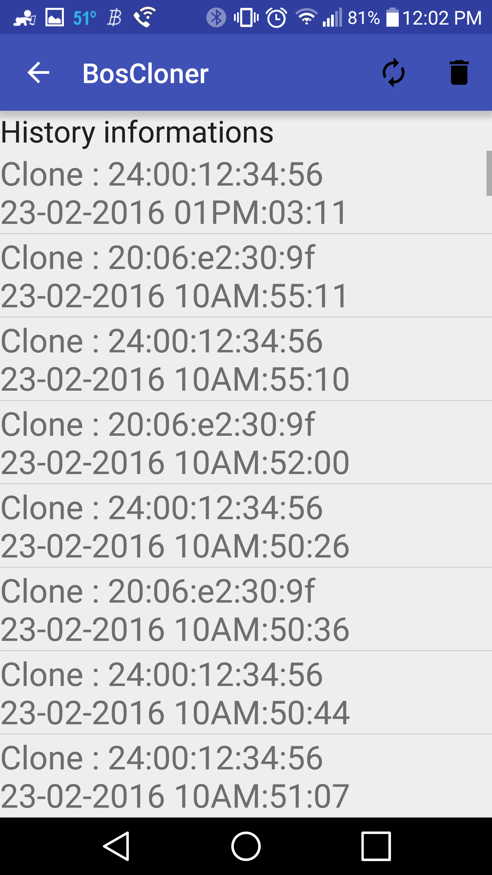
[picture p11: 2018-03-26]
Pics/Screenshot_2016-02-26-12-02-42.png

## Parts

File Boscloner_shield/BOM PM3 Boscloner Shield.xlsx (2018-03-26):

# | Quantity | Designator | Value | Description | Manufacturer | Manufacturer Part Number | Supplier 1 | Supplier Part Number 1 | #Column Name Error:Accept Replacement | Supplier Unit Price 1 | Supplier Subtotal 1
1 | 1 | U1 |  | IC MCU ARM 512KB FLASH 64LQFP | Freescale Semiconductor | MK22FN512VLH12 | Digi-Key | MK22FN512VLH12-ND |  | $6.07 | $6.07
2 | 4 | DC1, DC2, DC3, DC4 |  | LED ALINGAP RED CLEAR 0603 SMD | Dialight | 598-8010-107F | Digi-Key | 350-2029-6-ND |  | $0.45 | $1.80
3 | 5 | C1, C4, C6, C7, C8 | .1uF | .10uF X7R 20% (MLCC) - SMD/SMT 0603 25volts | TDK | C1608X7R1E104MT | Mouser | 810-C1608X7R1E104M |  | $0.27 | $1.35
4 | 1 | P1 |  | CONN HDR 1.27MM VERT AU 10POS | Harwin Inc | M50-3500542 | Digi-Key | 952-1383-ND |  | $1.17 | $1.17
5 | 1 | J3 |  | CONN MICRO SD CARD PUSH-PULL R/A | Molex, LLC | 475710001 | Digi-Key | WM9731CT-ND |  | $0.98 | $0.98
6 | 5 | C12, C13, C14, C15, C16 |  | CAP CER 2.2UF 6.3V X5R 0603 | Murata Electronics North America | GRM188R60J225KE19D | Digi-Key | 490-1552-1-ND |  | $0.13 | $0.65
7 | 1 | J2 |  | CONN USB MICRO B RECPT SMT R/A | FCI | 10118192-0001LF | Digi-Key | 609-4613-6-ND |  | $0.46 | $0.46
8 | 4 | R3, R4, R5, R10 | 330 | RES 330 OHM 1/10W 1% 0603 SMD | Panasonic Electronic Components | ERJ-3EKF3300V | Digi-Key | P330HCT-ND |  | $0.10 | $0.40
9 | 2 | PB1, PB2 | FSM4JSMATR | SWITCH TACTILE SPST-NO 0.05A 12V | TE Connectivity | FSM4JSMA | Digi-Key | 450-1129-ND |  | $0.20 | $0.40
10 | 1 | U2 |  | IC REG LDO 3V 250MA SOT23-3 | Microchip Technology | MCP1700T-3002E/TT | Digi-Key | MCP1700T-3002E/TTCT-ND |  | $0.37 | $0.37
11 | 10 | R1, R2, R6, R7, R8, R9, R11, R12, R13, R14 | 10k | 10k Thick Film Resistors - SMD 1/10watt 10Kohms 1% | Vishay Dale | CRCW060310K0FKEA | Digi-Key | 541-10.0KHCT-ND |  | $0.03 | $0.30
12 | 1 | J1 |  | CONN HEADER PH SIDE 3POS 2MM | JST Sales America Inc. | S3B-PH-K-S(LF)(SN) | Digi-Key | 455-1720-ND |  | $0.18 | $0.18
13 | 1 | R15 | 390k | 390Kohms 5% Thick Film Resistors - SMD 0805 Tol | Panasonic Electronic Components | ERJ-6GEYJ394V | Mouser | 667-ERJ-6GEYJ394V |  | $0.04 | $0.04
14 | 5 | C2, C3, C5, C9, C17 |  | 10uF 16Volts 10% (MLCC) - SMD/SMT | Murata | GRM21BR61C106KE15K | Mouser
15 | 10 | D1, M1, M2, M3, M?, P2, P3, P4, P7, U3 |  | 304020034, BT-HC-05/06, [NoValue], OLED_128x64_1_3_ADA, 1.3" 128x64 SSD1306 OLED module, Header 2 pin, Header 8 pin, Header pin, Header 8 pin, BT-HC-05/06 |  |  | Seeed Studio OPL | 304020034

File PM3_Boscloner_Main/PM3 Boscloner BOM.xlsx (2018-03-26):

Qty | Reference Designators | Value | Min Qty | P/N | Description
20 | C1, C4, C18, C19, C21, C22, C23, C24, C25, C26, C28, C29, C30, C31, C32, C44, C46, C47, C10, C45 | 33n | 20 | 490-1528-1-ND | CAP CER 33000PF 16V 10% X7R 0603
5 | C2, C3, C6, C7, C14 | 22p | 10 | 490-1335-1-ND | CAP CER 22PF 100V 5% C0G 0603
1 | C5 | 2n | 10 | 490-1458-1-ND | CAP CER 2000PF 50V 5% C0G 0603
7 | C8, C11, C12, C16, C39, C42, C43 | 1n | 10 | 445-2312-1-ND | CAP CER 1000PF 100V C0G 5% 0603
6 | C13, C17, C20, C36, C40, C41
1 | C15 | 130p | 10 | 490-1354-1-ND | CAP CER 130PF 100V 5% C0G 0603
4 | C9, C27, C33, C34 | 4u7 | 10 | 587-1392-1-ND | CAP CER 4.7UF 16V 10% X7R 1210
1 | C35 | 100p | 10 | 490-1351-1-ND | CAP CER 100PF 100V 5% C0G 0603
2 | C37, C38 | 100u | 5 | PCE3783CT-ND | CAP ELECT 100UF 16V 20% FK SMD
2 | D3, D2 |  | 2 | 497-2529-1-ND | DIODE SCHOTTKY 70V 70MA SOT-23
2 | D10, D11 |  | 2 | BZX84C47-FDICT-ND | DIODE ZENER 47V 350MW SOT23-3
2 | D1, D7 |  | 2 | BAS21INCT-ND | DIODE SWITCHING 200V SOT-23
1 | D4 |  | 1 | 160-1434-1-ND | LED YELLOW ORANGE CLEAR 0603 SMD
1 | D5 |  | 1 | 754-1357-1-ND | LED GREEN CLEAR 0603 SMD
2 | D6, D9 |  | 2 | 160-1436-1-ND | LED SUPER RED CLEAR 0603 SMD
1 | D8 |  | 1 | ESDA6V1L-TPCT-ND | TVS ESD 6.1V 300W SOT-23
1 | IC1 |  | 1 | 122-1513-5-ND | XC2S30-5VQG100C FPGA 2.5V 216 CLB'S 100-VQFP
1 | IC2 |  | 1 | AT91SAM7S256AU001-ND | IC ARM7 MCU 32BIT 256K 64LQFP | AT91SAM7S256D-AU-ND
2 | IC3, IC13 |  | 2 | MCP1824T-3302E/OTCT-ND | IC LDO REG 300MA 3.3V SOT23-5 | AP2210K-3.3TRG1DICT-ND
1 | IC4 |  | 1 | NC7SZ04M5XCT-ND | IC INVERTER SGL TINYLOGIC SOT-23
1 | IC5 |  | 1 | 296-18147-1-ND | IC COMPARATOR R-R HI-SPD SOT23-8
1 | IC6 |  | 1 | MCP6294-E/ST-ND | IC OPAMP 2.4V QUAD R-R 14TSSOP
1 | IC7 |  | 1 | MCP100T-300I/TTCT-ND | IC SUPERVISOR ACTIVE LOW SOT23-3
1 | IC8 |  | 1 | 296-2184-5-ND | TLC5540IPW 8-BIT PAR HS A/D CONV 24TSSOP
2 | IC9, IC10 |  | 2 | 497-2916-1-ND | IC BUFF/DVR TRI-ST DUAL 20TSSOP
1 | IC11 |  | 1 | 497-7382-1-ND | M74HC4066TTR SWITCH QUAD 2X1 14TSSOP | MC74VHC4066 - mouser: 863-MC74VHC4066DTR2G
1 | IC12 |  | 1 | LP2989IM-2.5-ND | IC REGULATOR MICROPWR LDO 8-SOIC | LP2989IM-2.5/NOPB, digikey: LP2989IM-2.5/NOPB-ND
1 | IC14 |  | 1 | AD8052ARMZ-ND | IC OPAMP VF R-R DUAL LDIST 8MSOP
1 | Q1 |  | 1 | 568-1741-1-ND | TRANS 2N3904 NPN SW 200MA 40V SOT23
1 | Q2 |  | 1 | IRF7307PBFCT-ND | IRF7307 MOSFET N+P 20V 4.3A 8-SOIC
2 | R1, R42 | 1M | 10 | 311-1.00MHRCT-ND | RES 1.00M OHM 1/10W 1% 0603 SMD
3 | R2, R52, R54 | 100 | 10 | 311-100HRCT-ND | RES 100 OHM 1/10W 1% 0603 SMD
6 | R3, R53, R24, R25, R26, R55 | 330 | 10 | 311-330HRCT-ND | RES 330 OHM 1/10W 1% 0603 SMD
2 | R4, R5 | 27 | 10 | 311-27.0HRCT-ND | RES 27.0 OHM 1/10W 1% 0603 SMD
1 | R6 | 1K5 | 10 | 311-1.50KHRCT-ND | RES 1.50K OHM 1/10W 1% 0603 SMD
16 | R7, R8, R13, R14, R15, R17, R18, R19, R34, R40, R45, R46,R47, R50, R56, R57 | 10K | 20 | 311-10.0KHRCT-ND | RES 10.0K OHM 1/10W 1% 0603 SMD
3 | R9, R10, R12 | 100K | 10 | 311-100KHRCT-ND | RES 100K OHM 1/10W 1% 0603 SMD
1 | R11 | 510K | 10 | 311-510KHRCT-ND | RES 510K OHM 1/10W 1% 0603 SMD
4 | R16, R32, R35, R58 | zerohm | 10 | 311-0.0GRCT-ND | RES 0.0 OHM 1/10W 5% 0603 SMD
2 | R20, R31 | 240K | 10 | 311-240KHRCT-ND | RES 240K OHM 1/10W 1% 0603 SMD
1 | R21 | 24K | 10 | 311-24.0KHRCT-ND | RES 24.0K OHM 1/10W 1% 0603 SMD
4 | R22, R27, R28, R29, R45, R46 | 33 | 10 | 311-33.0HRCT-ND | RES 33.0 OHM 1/10W 1% 0603 SMD
4 | R23, R39, R43, R44 | 1K | 10 | 311-1.00KHRCT-ND | RES 1.00K OHM 1/10W 1% 0603 SMD
2 | R30, R41 | 10M | 10 | 311-10.0MHRCT-ND | RES 10.0M OHM 1/10W 1% 0603 SMD
3 | R33, R49, R51 | 2K4 | 10 | 311-2.40KHRCT-ND | RES 2.40K OHM 1/10W 1% 0603 SMD
4 | R36, R37, R38, R48
1 | R59 | 2K3 | 10 | 311-3.30KHRCT-ND | RES 3.30K OHM 1/10W 1% 0603 SMD
1 | RLY1 |  | 1 | Z827-ND | RELAY DPDT 5VDC 1A SMD | 255-1010-5-ND
1 | SV1 |  | 1 | H2959CT-ND | CONN RECEPT MINI USB2.0 5POS
1 | SV2 |  | 1 | H10488-ND | CONN RECEPT MQ172 4POS SMT LOW PROFILE
1 | SV3 |  | 1 | S9172-ND | CONN HEADER 2.54MM 20POS GOLD
1 | SV5
1 | SW1 |  | 1 | P12969SCT-ND | SWITCH LT 8MM 500GF H=6.5MM SMD
7 | TP1, TP2, TP3, TP4, TP5, TP7, TP8 |  | 7 | 5015KCT-ND | PC TEST POINT MINIATURE SMT
1 | TP6 |  | 10 | 5006K-ND | TEST POINT PC COMPACT .063"D BLK
1 | U1 |  | 10 | 445-1566-1-ND | FERRITE CHIP 30 OHM 6A 0805
1 | XT1 | 13.56 MHz | 1 | 887-1083-1-ND | CRYSTAL 13.560 MHZ 18PF SMD
1 | XT2 | 16 MHz | 1 | 887-1086-1-ND | CRYSTAL 16.000 MHZ 18PF SMD
150

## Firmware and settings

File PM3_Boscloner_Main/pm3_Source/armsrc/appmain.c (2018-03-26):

//-----------------------------------------------------------------------------
// Jonathan Westhues, Mar 2006
// Edits by Gerhard de Koning Gans, Sep 2007 (##)
//
// This code is licensed to you under the terms of the GNU GPL, version 2 or,
// at your option, any later version. See the LICENSE.txt file for the text of
// the license.
//-----------------------------------------------------------------------------
// The main application code. This is the first thing called after start.c
// executes.
//-----------------------------------------------------------------------------

#include "usb_cdc.h"
#include "cmd.h"

#include "proxmark3.h"
#include "apps.h"
#include "util.h"
#include "printf.h"
#include "string.h"

#include <stdarg.h>

#include "legicrf.h"
#include <hitag2.h>

#ifdef WITH_LCD
#include "LCD.h"
#endif

#include "boscloner.h"

#define abs(x) ( ((x)<0) ? -(x) : (x) )

//=============================================================================
// A buffer where we can queue things up to be sent through the FPGA, for
// any purpose (fake tag, as reader, whatever). We go MSB first, since that
// is the order in which they go out on the wire.
//=============================================================================

uint8_t ToSend[512];
int ToSendMax;
static int ToSendBit;
struct common_area common_area __attribute__((section(".commonarea")));

void BufferClear(void) {
	memset(BigBuf, 0, sizeof(BigBuf));
	Dbprintf("Buffer cleared (%i bytes)", sizeof(BigBuf));
}

void ToSendReset(void) {
	ToSendMax = -1;
	ToSendBit = 8;
}

void ToSendStuffBit(int b) {
	if (ToSendBit >= 8) {
		ToSendMax++;
		ToSend[ToSendMax] = 0;
		ToSendBit = 0;
	}

	if (b) {
		ToSend[ToSendMax] |= (1 << (7 - ToSendBit));
	}

	ToSendBit++;

	if (ToSendBit >= sizeof(ToSend)) {
		ToSendBit = 0;
		DbpString("ToSendStuffBit overflowed!");
	}
}

//=============================================================================
// Debug print functions, to go out over USB, to the usual PC-side client.
//=============================================================================

void DbpString(char *str) {
	byte_t len = strlen(str);
	cmd_send(CMD_DEBUG_PRINT_STRING, len, 0, 0, (byte_t*) str, len);
//	/* this holds up stuff unless we're connected to usb */
//	if (!UsbConnected())
//		return;
//
//	UsbCommand c;
//	c.cmd = CMD_DEBUG_PRINT_STRING;
//	c.arg[0] = strlen(str);
//	if(c.arg[0] > sizeof(c.d.asBytes)) {
//		c.arg[0] = sizeof(c.d.asBytes);
//	}
//	memcpy(c.d.asBytes, str, c.arg[0]);
//
//	UsbSendPacket((uint8_t *)&c, sizeof(c));
//	// TODO fix USB so stupid things like this aren't req'd
//	SpinDelay(50);
}

#if 0
void DbpIntegers(int x1, int x2, int x3)
{
	cmd_send(CMD_DEBUG_PRINT_INTEGERS,x1,x2,x3,0,0);
//	/* this holds up stuff unless we're connected to usb */
//	if (!UsbConnected())
//		return;
//
//	UsbCommand c;
//	c.cmd = CMD_DEBUG_PRINT_INTEGERS;
//	c.arg[0] = x1;
//	c.arg[1] = x2;
//	c.arg[2] = x3;
//
//	UsbSendPacket((uint8_t *)&c, sizeof(c));
//	// XXX
//	SpinDelay(50);
}
#endif

void Dbprintf(const char *fmt, ...) {
// should probably limit size here; oh well, let's just use a big buffer
	char output_string[128];
	va_list ap;

	va_start(ap, fmt);
	kvsprintf(fmt, output_string, 10, ap);
	va_end(ap);

	DbpString(output_string);
}

// prints HEX & ASCII
void Dbhexdump(int len, uint8_t *d, bool bAsci) {
	int l = 0, i;
	char ascii[9];

	while (len > 0) {
		if (len > 8)
			l = 8;
		else
			l = len;

		memcpy(ascii, d, l);
		ascii[l] = 0;

		// filter safe ascii
		for (i = 0; i < l; i++)
			if (ascii[i] < 32 || ascii[i] > 126)
				ascii[i] = '.';

		if (bAsci) {
			Dbprintf("%-8s %*D", ascii, l, d, " ");
		} else {
			Dbprintf("%*D", l, d, " ");
		}

		len -= 8;
		d += 8;
	}
}

//-----------------------------------------------------------------------------
// Read an ADC channel and block till it completes, then return the result
// in ADC units (0 to 1023). Also a routine to average 32 samples and
// return that.
//-----------------------------------------------------------------------------
static int ReadAdc(int ch) {
	uint32_t d;

	AT91C_BASE_ADC->ADC_CR = AT91C_ADC_SWRST;
	AT91C_BASE_ADC->ADC_MR = ADC_MODE_PRESCALE(32) | ADC_MODE_STARTUP_TIME(16)
			| ADC_MODE_SAMPLE_HOLD_TIME(8);
	AT91C_BASE_ADC->ADC_CHER = ADC_CHANNEL(ch);

	AT91C_BASE_ADC->ADC_CR = AT91C_ADC_START;
	while (!(AT91C_BASE_ADC->ADC_SR & ADC_END_OF_CONVERSION(ch)))
		;
	d = AT91C_BASE_ADC->ADC_CDR[ch];

	return d;
}

int AvgAdc(int ch) // was static - merlok
{
	int i;
	int a = 0;

	for (i = 0; i < 32; i++) {
		a += ReadAdc(ch);
	}

	return (a + 15) >> 5;
}

void MeasureAntennaTuning(void) {
	uint8_t *dest = (uint8_t *) BigBuf + FREE_BUFFER_OFFSET;
	int i, adcval = 0, peak = 0, peakv = 0, peakf = 0; //ptr = 0 
	int vLf125 = 0, vLf134 = 0, vHf = 0;	// in mV

//	UsbCommand c;

	LED_B_ON();
	DbpString("Measuring antenna characteristics, please wait...");
	memset(dest, 0, sizeof(FREE_BUFFER_SIZE));

	/*
	 * Sweeps the useful LF range of the proxmark from
	 * 46.8kHz (divisor=255) to 600kHz (divisor=19) and
	 * read the voltage in the antenna, the result left
	 * in the buffer is a graph which should clearly show
	 * the resonating frequency of your LF antenna
	 * ( hopefully around 95 if it is tuned to 125kHz!)
	 */

	FpgaWriteConfWord(FPGA_MAJOR_MODE_LF_READER);
	for (i = 255; i > 19; i--) {
		WDT_HIT();
		FpgaSendCommand(FPGA_CMD_SET_DIVISOR, i);
		SpinDelay(20);
		// Vref = 3.3V, and a 10000:240 voltage divider on the input
		// can measure voltages up to 137500 mV
		adcval = ((137500 * AvgAdc(ADC_CHAN_LF)) >> 10);
		if (i == 95)
			vLf125 = adcval; // voltage at 125Khz
		if (i == 89)
			vLf134 = adcval; // voltage at 134Khz

		dest[i] = adcval >> 8; // scale int to fit in byte for graphing purposes
		if (dest[i] > peak) {
			peakv = adcval;
			peak = dest[i];
			peakf = i;
			//ptr = i;
		}
	}

	LED_A_ON();
	// Let the FPGA drive the high-frequency antenna around 13.56 MHz.
	FpgaWriteConfWord(FPGA_MAJOR_MODE_HF_READER_RX_XCORR);
	SpinDelay(20);
	// Vref = 3300mV, and an 10:1 voltage divider on the input
	// can measure voltages up to 33000 mV
	vHf = (33000 * AvgAdc(ADC_CHAN_HF)) >> 10;

//	c.cmd = CMD_MEASURED_ANTENNA_TUNING;
//	c.arg[0] = (vLf125 << 0) | (vLf134 << 16);
//	c.arg[1] = vHf;
//	c.arg[2] = peakf | (peakv << 16);

	DbpString("Measuring complete, sending report back to host");
	cmd_send(CMD_MEASURED_ANTENNA_TUNING, vLf125 | (vLf134 << 16), vHf,
			peakf | (peakv << 16), 0, 0);
//	UsbSendPacket((uint8_t *)&c, sizeof(c));
	FpgaWriteConfWord(FPGA_MAJOR_MODE_OFF);
	LED_A_OFF();
	LED_B_OFF();
	return;
}

void MeasureAntennaTuningHf(void) {
	int vHf = 0;	// in mV

	DbpString("Measuring HF antenna, press button to exit");

	for (;;) {
		// Let the FPGA drive the high-frequency antenna around 13.56 MHz.
		FpgaWriteConfWord(FPGA_MAJOR_MODE_HF_READER_RX_XCORR);
		SpinDelay(20);
		// Vref = 3300mV, and an 10:1 voltage divider on the input
		// can measure voltages up to 33000 mV
		vHf = (33000 * AvgAdc(ADC_CHAN_HF)) >> 10;

		Dbprintf("%d mV", vHf);
		if (BUTTON_PRESS())
			break;
	}
	DbpString("cancelled");
}

void SimulateTagHfListen(void) {
	uint8_t *dest = (uint8_t *) BigBuf + FREE_BUFFER_OFFSET;
	uint8_t v = 0;
	int i;
	int p = 0;

	// We're using this mode just so that I can test it out; the simulated
	// tag mode would work just as well and be simpler.
	FpgaWriteConfWord(
			FPGA_MAJOR_MODE_HF_READER_RX_XCORR | FPGA_HF_READER_RX_XCORR_848_KHZ
					| FPGA_HF_READER_RX_XCORR_SNOOP);

	// We need to listen to the high-frequency, peak-detected path.
	SetAdcMuxFor(GPIO_MUXSEL_HIPKD);

	FpgaSetupSsc();

	i = 0;
	for (;;) {
		if (AT91C_BASE_SSC->SSC_SR & (AT91C_SSC_TXRDY)) {
			AT91C_BASE_SSC->SSC_THR = 0xff;
		}
		if (AT91C_BASE_SSC->SSC_SR & (AT91C_SSC_RXRDY)) {
			uint8_t r = (uint8_t) AT91C_BASE_SSC->SSC_RHR;

			v <<= 1;
			if (r & 1) {
				v |= 1;
			}
			p++;

			if (p >= 8) {
				dest[i] = v;
				v = 0;
				p = 0;
				i++;

				if (i >= FREE_BUFFER_SIZE) {
					break;
				}
			}
		}
	}
	DbpString("simulate tag (now type bitsamples)");
}

void ReadMem(int addr) {
	const uint8_t *data = ((uint8_t *) addr);

	Dbprintf("%x: %02x %02x %02x %02x %02x %02x %02x %02x", addr, data[0],
			data[1], data[2], data[3], data[4], data[5], data[6], data[7]);
}

/* osimage version information is linked in */
extern struct version_information version_information;
/* bootrom version information is pointed to from _bootphase1_version_pointer */
extern char *_bootphase1_version_pointer, _flash_start, _flash_end;
void SendVersion(void) {
	char temp[48]; /* Limited data payload in USB packets */
	DbpString("Prox/RFID mark3 RFID instrument");

	/* Try to find the bootrom version information. Expect to find a pointer at
	 * symbol _bootphase1_version_pointer, perform slight sanity checks on the
	 * pointer, then use it.
	 */
	char *bootrom_version = *(char**) &_bootphase1_version_pointer;
	if (bootrom_version < &_flash_start || bootrom_version >= &_flash_end) {
		DbpString("bootrom version information appears invalid");
	} else {
		FormatVersionInformation(temp, sizeof(temp), "bootrom: ",
				bootrom_version);
		DbpString(temp);
	}

	FormatVersionInformation(temp, sizeof(temp), "os: ", &version_information);
	DbpString(temp);

	FpgaGatherVersion(temp, sizeof(temp));
	DbpString(temp);
	// Send Chip ID
	cmd_send(CMD_ACK, *(AT91C_DBGU_CIDR), 0, 0, NULL, 0);
}

#ifdef WITH_LF
// samy's sniff and repeat routine
void SamyRun()
{
	DbpString("Stand-alone mode! No PC necessary.");

	// 3 possible options? no just 2 for now
#define OPTS 2

	int high[OPTS], low[OPTS];

	// Oooh pretty -- notify user we're in elite samy mode now
	LED(LED_RED, 200);
	LED(LED_ORANGE, 200);
	LED(LED_GREEN, 200);
	LED(LED_ORANGE, 200);
	LED(LED_RED, 200);
	LED(LED_ORANGE, 200);
	LED(LED_GREEN, 200);
	LED(LED_ORANGE, 200);
	LED(LED_RED, 200);

	int selected = 0;
	int playing = 0;

	// Turn on selected LED
	LED(selected + 1, 0);

	for (;;)
	{
//		UsbPoll(FALSE);
		usb_poll();
		WDT_HIT();

		// Was our button held down or pressed?
		int button_pressed = BUTTON_HELD(1000);
		SpinDelay(300);

		// Button was held for a second, begin recording
		if (button_pressed > 0)
		{
			LEDsoff();
			LED(selected + 1, 0);
			LED(LED_RED2, 0);

			// record
			DbpString("Starting recording");

			// wait for button to be released
			while(BUTTON_PRESS())
			WDT_HIT();

			/* need this delay to prevent catching some weird data */
			SpinDelay(500);

			CmdHIDdemodFSK(1, &high[selected], &low[selected], 0);
			Dbprintf("Recorded %x %x %x", selected, high[selected], low[selected]);

			LEDsoff();
			LED(selected + 1, 0);
			// Finished recording

			// If we were previously playing, set playing off
			// so next button push begins playing what we recorded
			playing = 0;
		}

		// Change where to record (or begin playing)
		else if (button_pressed)
		{
			// Next option if we were previously playing
			if (playing)
			selected = (selected + 1) % OPTS;
			playing = !playing;

			LEDsoff();
			LED(selected + 1, 0);

			// Begin transmitting
			if (playing)
			{
				LED(LED_GREEN, 0);
				DbpString("Playing");
				// wait for button to be released
				while(BUTTON_PRESS())
				WDT_HIT();
				Dbprintf("%x %x %x", selected, high[selected], low[selected]);
				CmdHIDsimTAG(high[selected], low[selected], 0);
				DbpString("Done playing");
				if (BUTTON_HELD(1000) > 0)
				{
					DbpString("Exiting");
					LEDsoff();
					return;
				}

				/* We pressed a button so ignore it here with a delay */
				SpinDelay(300);

				// when done, we're done playing, move to next option
				selected = (selected + 1) % OPTS;
				playing = !playing;
				LEDsoff();
				LED(selected + 1, 0);
			}
			else
			while(BUTTON_PRESS())
			WDT_HIT();
		}
	}
}
#endif

/*
 OBJECTIVE
 Listen and detect an external reader. Determine the best location
 for the antenna.

 INSTRUCTIONS:
 Inside the ListenReaderField() function, there is two mode.
 By default, when you call the function, you will enter mode 1.
 If you press the PM3 button one time, you will enter mode 2.
 If you press the PM3 button a second time, you will exit the function.

 DESCRIPTION OF MODE 1:
 This mode just listens for an external reader field and lights up green
 for HF and/or red for LF. This is the original mode of the detectreader
 function.

 DESCRIPTION OF MODE 2:
 This mode will visually represent, using the LEDs, the actual strength of the
 current compared to the maximum current detected. Basically, once you know
 what kind of external reader is present, it will help you spot the best location to place
 your antenna. You will probably not get some good results if there is a LF and a HF reader
 at the same place! :-)

 LIGHT SCHEME USED:
 */
static const char LIGHT_SCHEME[] = { 0x0, /* ----     | No field detected */
0x1, /* X---     | 14% of maximum current detected */
0x2, /* -X--     | 29% of maximum current detected */
0x4, /* --X-     | 43% of maximum current detected */
0x8, /* ---X     | 57% of maximum current detected */
0xC, /* --XX     | 71% of maximum current detected */
0xE, /* -XXX     | 86% of maximum current detected */
0xF, /* XXXX     | 100% of maximum current detected */
};
static const int LIGHT_LEN = sizeof(LIGHT_SCHEME) / sizeof(LIGHT_SCHEME[0]);

void ListenReaderField(int limit) {
	int lf_av, lf_av_new, lf_baseline = 0, lf_count = 0, lf_max;
	int hf_av, hf_av_new, hf_baseline = 0, hf_count = 0, hf_max;
	int mode = 1, display_val, display_max, i;

#define LF_ONLY		1
#define HF_ONLY		2

	LEDsoff();

	lf_av = lf_max = ReadAdc(ADC_CHAN_LF);

	if (limit != HF_ONLY) {
		Dbprintf("LF 125/134 Baseline: %d", lf_av);
		lf_baseline = lf_av;
	}

	hf_av = hf_max = ReadAdc(ADC_CHAN_HF);

	if (limit != LF_ONLY) {
		Dbprintf("HF 13.56 Baseline: %d", hf_av);
		hf_baseline = hf_av;
	}

	for (;;) {
		if (BUTTON_PRESS()) {
			SpinDelay(500);
			switch (mode) {
			case 1:
				mode = 2;
				DbpString("Signal Strength Mode");
				break;
			case 2:
			default:
				DbpString("Stopped");
				LEDsoff();
				return;
				break;
			}
		}
		WDT_HIT();

		if (limit != HF_ONLY) {
			if (mode == 1) {
				if (abs(lf_av - lf_baseline) > 10)
					LED_D_ON();
				else
					LED_D_OFF();
			}

			++lf_count;
			lf_av_new = ReadAdc(ADC_CHAN_LF);
			// see if there's a significant change
			if (abs(lf_av - lf_av_new) > 10) {
				Dbprintf("LF 125/134 Field Change: %x %x %x", lf_av, lf_av_new,
						lf_count);
				lf_av = lf_av_new;
				if (lf_av > lf_max)
					lf_max = lf_av;
				lf_count = 0;
			}
		}

		if (limit != LF_ONLY) {
			if (mode == 1) {
				if (abs(hf_av - hf_baseline) > 10)
					LED_B_ON();
				else
					LED_B_OFF();
			}

			++hf_count;
			hf_av_new = ReadAdc(ADC_CHAN_HF);
			// see if there's a significant change
			if (abs(hf_av - hf_av_new) > 10) {
				Dbprintf("HF 13.56 Field Change: %x %x %x", hf_av, hf_av_new,
						hf_count);
				hf_av = hf_av_new;
				if (hf_av > hf_max)
					hf_max = hf_av;
				hf_count = 0;
			}
		}

		if (mode == 2) {
			if (limit == LF_ONLY) {
				display_val = lf_av;
				display_max = lf_max;
			} else if (limit == HF_ONLY) {
				display_val = hf_av;
				display_max = hf_max;
			} else { /* Pick one at random */
				if ((hf_max - hf_baseline) > (lf_max - lf_baseline)) {
					display_val = hf_av;
					display_max = hf_max;
				} else {
					display_val = lf_av;
					display_max = lf_max;
				}
			}
			for (i = 0; i < LIGHT_LEN; i++) {
				if (display_val >= ((display_max / LIGHT_LEN) * i)
						&& display_val
								<= ((display_max / LIGHT_LEN) * (i + 1))) {
					if (LIGHT_SCHEME[i] & 0x1)
						LED_C_ON();
					else
						LED_C_OFF();
					if (LIGHT_SCHEME[i] & 0x2)
						LED_A_ON();
					else
						LED_A_OFF();
					if (LIGHT_SCHEME[i] & 0x4)
						LED_B_ON();
					else
						LED_B_OFF();
					if (LIGHT_SCHEME[i] & 0x8)
						LED_D_ON();
					else
						LED_D_OFF();
					break;
				}
			}
		}
	}
}

void UsbPacketReceived(uint8_t *packet, int len) {
	UsbCommand *c = (UsbCommand *) packet;

//  Dbprintf("received %d bytes, with command: 0x%04x and args: %d %d %d",len,c->cmd,c->arg[0],c->arg[1],c->arg[2]);

	switch (c->cmd) {
#ifdef WITH_LF
	case CMD_ACQUIRE_RAW_ADC_SAMPLES_125K:
	AcquireRawAdcSamples125k(c->arg[0]);
	cmd_send(CMD_ACK,0,0,0,0,0);
	break;
	case CMD_MOD_THEN_ACQUIRE_RAW_ADC_SAMPLES_125K:
	ModThenAcquireRawAdcSamples125k(c->arg[0],c->arg[1],c->arg[2],c->d.asBytes);
	break;
	case CMD_HID_DEMOD_FSK:
	CmdHIDdemodFSK(0, 0, 0, 1);					// Demodulate HID tag
	break;
	case CMD_HID_SIM_TAG:
	CmdHIDsimTAG(c->arg[0], c->arg[1], 1);// Simulate HID tag by ID
	break;
	case CMD_HID_CLONE_TAG:// Clone HID tag by ID to T55x7
	//!
	Dbprintf("arg0:%s arg1:%s arg2:%s c->d.asBytes:%x", c->arg[0], c->arg[1], c->arg[2], c->d.asBytes[0]);
	CopyHIDtoT55x7(c->arg[0], c->arg[1], c->arg[2], c->d.asBytes[0]);
	break;
	case CMD_EM410X_WRITE_TAG:
	WriteEM410x(c->arg[0], c->arg[1], c->arg[2]);
	break;
	case CMD_READ_TI_TYPE:
	ReadTItag();
	break;
	case CMD_WRITE_TI_TYPE:
	WriteTItag(c->arg[0],c->arg[1],c->arg[2]);
	break;
	case CMD_SIMULATE_TAG_125K:
	LED_A_ON();
	SimulateTagLowFrequency(c->arg[0], c->arg[1], 1);
	LED_A_OFF();
	break;
	case CMD_LF_SIMULATE_BIDIR:
	SimulateTagLowFrequencyBidir(c->arg[0], c->arg[1]);
	break;
	case CMD_INDALA_CLONE_TAG:// Clone Indala 64-bit tag by UID to T55x7
	CopyIndala64toT55x7(c->arg[0], c->arg[1]);
	break;
	case CMD_INDALA_CLONE_TAG_L:// Clone Indala 224-bit tag by UID to T55x7
	CopyIndala224toT55x7(c->d.asDwords[0], c->d.asDwords[1], c->d.asDwords[2], c->d.asDwords[3], c->d.asDwords[4], c->d.asDwords[5], c->d.asDwords[6]);
	break;
	case CMD_T55XX_READ_BLOCK:
	T55xxReadBlock(c->arg[1], c->arg[2],c->d.asBytes[0]);
	break;
	case CMD_T55XX_WRITE_BLOCK:
	T55xxWriteBlock(c->arg[0], c->arg[1], c->arg[2], c->d.asBytes[0]);
	break;
	case CMD_T55XX_READ_TRACE:// Clone HID tag by ID to T55x7
	T55xxReadTrace();
	break;
	case CMD_PCF7931_READ:// Read PCF7931 tag
	ReadPCF7931();
	cmd_send(CMD_ACK,0,0,0,0,0);
//      	UsbSendPacket((uint8_t*)&ack, sizeof(ack));
	break;
	case CMD_EM4X_READ_WORD:
	EM4xReadWord(c->arg[1], c->arg[2],c->d.asBytes[0]);
	break;
	case CMD_EM4X_WRITE_WORD:
	EM4xWriteWord(c->arg[0], c->arg[1], c->arg[2], c->d.asBytes[0]);
	break;
#endif

#ifdef WITH_HITAG
	case CMD_SNOOP_HITAG: // Eavesdrop Hitag tag, args = type
	SnoopHitag(c->arg[0]);
	break;
	case CMD_SIMULATE_HITAG:// Simulate Hitag tag, args = memory content
	SimulateHitagTag((bool)c->arg[0],(byte_t*)c->d.asBytes);
	break;
	case CMD_READER_HITAG:// Reader for Hitag tags, args = type and function
	ReaderHitag((hitag_function)c->arg[0],(hitag_data*)c->d.asBytes);
	break;
#endif

#ifdef WITH_ISO15693
	case CMD_ACQUIRE_RAW_ADC_SAMPLES_ISO_15693:
	AcquireRawAdcSamplesIso15693();
	break;
	case CMD_RECORD_RAW_ADC_SAMPLES_ISO_15693:
	RecordRawAdcSamplesIso15693();
	break;

	case CMD_ISO_15693_COMMAND:
	DirectTag15693Command(c->arg[0],c->arg[1],c->arg[2],c->d.asBytes);
	break;

	case CMD_ISO_15693_FIND_AFI:
	BruteforceIso15693Afi(c->arg[0]);
	break;

	case CMD_ISO_15693_DEBUG:
	SetDebugIso15693(c->arg[0]);
	break;

	case CMD_READER_ISO_15693:
	ReaderIso15693(c->arg[0]);
	break;
	case CMD_SIMTAG_ISO_15693:
	SimTagIso15693(c->arg[0]);
	break;
#endif

#ifdef WITH_LEGICRF
	case CMD_SIMULATE_TAG_LEGIC_RF:
	LegicRfSimulate(c->arg[0], c->arg[1], c->arg[2]);
	break;

	case CMD_WRITER_LEGIC_RF:
	LegicRfWriter(c->arg[1], c->arg[0]);
	break;

	case CMD_READER_LEGIC_RF:
	LegicRfReader(c->arg[0], c->arg[1]);
	break;
#endif

#ifdef WITH_ISO14443b
	case CMD_ACQUIRE_RAW_ADC_SAMPLES_ISO_14443:
	AcquireRawAdcSamplesIso14443(c->arg[0]);
	break;
	case CMD_READ_SRI512_TAG:
	ReadSTMemoryIso14443(0x0F);
	break;
	case CMD_READ_SRIX4K_TAG:
	ReadSTMemoryIso14443(0x7F);
	break;
	case CMD_SNOOP_ISO_14443:
	SnoopIso14443();
	break;
	case CMD_SIMULATE_TAG_ISO_14443:
	SimulateIso14443Tag();
	break;
	case CMD_ISO_14443B_COMMAND:
	SendRawCommand14443B(c->arg[0],c->arg[1],c->arg[2],c->d.asBytes);
	break;
#endif
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

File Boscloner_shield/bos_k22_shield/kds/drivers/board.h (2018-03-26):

/*
 * Copyright (c) 2014, Freescale Semiconductor, Inc.
 * All rights reserved.
 *
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
 * o Neither the name of Freescale Semiconductor, Inc. nor the names of its
 *   contributors may be used to endorse or promote products derived from this
 *   software without specific prior written permission.
 *
 * THIS SOFTWARE IS PROVIDED BY THE COPYRIGHT HOLDERS AND CONTRIBUTORS "AS IS" AND
 * ANY EXPRESS OR IMPLIED WARRANTIES, INCLUDING, BUT NOT LIMITED TO, THE IMPLIED
 * WARRANTIES OF MERCHANTABILITY AND FITNESS FOR A PARTICULAR PURPOSE ARE
 * DISCLAIMED. IN NO EVENT SHALL THE COPYRIGHT HOLDER OR CONTRIBUTORS BE LIABLE FOR
 * ANY DIRECT, INDIRECT, INCIDENTAL, SPECIAL, EXEMPLARY, OR CONSEQUENTIAL DAMAGES
 * (INCLUDING, BUT NOT LIMITED TO, PROCUREMENT OF SUBSTITUTE GOODS OR SERVICES;
 * LOSS OF USE, DATA, OR PROFITS; OR BUSINESS INTERRUPTION) HOWEVER CAUSED AND ON
 * ANY THEORY OF LIABILITY, WHETHER IN CONTRACT, STRICT LIABILITY, OR TORT
 * (INCLUDING NEGLIGENCE OR OTHERWISE) ARISING IN ANY WAY OUT OF THE USE OF THIS
 * SOFTWARE, EVEN IF ADVISED OF THE POSSIBILITY OF SUCH DAMAGE.
 */

#if !defined(__BOARD_H__)
#define __BOARD_H__

#include <stdint.h>
#include "pin_mux.h"
#include "gpio_pins.h"

/* The board name */
#define BOARD_NAME                      "FRDM-K22F"

#define CLOCK_VLPR   1U
#define CLOCK_RUN    2U
#define CLOCK_HSRUN  3U
#define CLOCK_NUMBER_OF_CONFIGURATIONS 4U

#ifndef CLOCK_INIT_CONFIG
#define CLOCK_INIT_CONFIG CLOCK_HSRUN
#endif

#if (CLOCK_INIT_CONFIG == CLOCK_RUN)
#define CORE_CLOCK_FREQ 80000000U
#elif (CLOCK_INIT_CONFIG == CLOCK_HSRUN)
#define CORE_CLOCK_FREQ 120000000U
#else
#define CORE_CLOCK_FREQ 4000000U
#endif

/* OSC0 configuration. */
#define OSC0_XTAL_FREQ 8000000U
#define OSC0_SC2P_ENABLE_CONFIG  false
#define OSC0_SC4P_ENABLE_CONFIG  false
#define OSC0_SC8P_ENABLE_CONFIG  false
#define OSC0_SC16P_ENABLE_CONFIG false
#define MCG_HGO0   kOscGainLow
#define MCG_RANGE0 kOscRangeVeryHigh
#define MCG_EREFS0 kOscSrcOsc

/* EXTAL0 PTA18 */
#define EXTAL0_PORT   PORTA
#define EXTAL0_PIN    18
#define EXTAL0_PINMUX kPortPinDisabled

/* XTAL0 PTA19 */
#define XTAL0_PORT   PORTA
#define XTAL0_PIN    19
#define XTAL0_PINMUX kPortPinDisabled

/* RTC external clock configuration. */
#define RTC_XTAL_FREQ   32768U
#define RTC_SC2P_ENABLE_CONFIG       false
#define RTC_SC4P_ENABLE_CONFIG       false
#define RTC_SC8P_ENABLE_CONFIG       false
#define RTC_SC16P_ENABLE_CONFIG      false
#define RTC_OSC_ENABLE_CONFIG        true

#define BOARD_RTC_CLK_FREQUENCY     32768U;

/* The UART to use for debug messages. */
#ifndef BOARD_DEBUG_UART_INSTANCE
    #define BOARD_DEBUG_UART_INSTANCE   1
    #define BOARD_DEBUG_UART_BASEADDR   UART1
#endif
#ifndef BOARD_DEBUG_UART_BAUD
    #define BOARD_DEBUG_UART_BAUD       115200
#endif

/* This define to use for power manager demo */
#define BOARD_LOW_POWER_UART_BAUD       9600

#define BOARD_USE_UART

#define PM_DBG_UART_IRQ_HANDLER         UART1_RX_TX_IRQHandler

#define PM_DBG_UART_IRQn                UART1_RX_TX_IRQn

/* Define the port interrupt number for the board switches */
#define BOARD_SW_GPIO               kGpioSW3
#define BOARD_SW_IRQ_NUM            PORTB_IRQn
#define BOARD_SW_IRQ_HANDLER        PORTB_IRQHandler
#define BOARD_SW_NAME               "SW3"
/* Define feature for the low_power_demo */
#define FSL_FEATURE_HAS_VLLS2 (1)

/* Define print statement to inform user which switch to press for
 * power_manager_hal_demo and power_manager_rtos_demo
 */
#define PRINT_LLWU_SW_NUM \
  PRINTF("SW2")

/* Defines the llwu pin number for board switch which is used in power_manager_demo. */
#define BOARD_SW_HAS_LLWU_PIN        1
#define BOARD_SW_LLWU_EXT_PIN        kLlwuWakeupPin6
/* Switch port base address and IRQ handler name. Used by power_manager_demo */
#define BOARD_SW_LLWU_PIN            1
#define BOARD_SW_LLWU_BASE           PORTC
#define BOARD_SW_LLWU_IRQ_HANDLER    PORTC_IRQHandler
#define BOARD_SW_LLWU_IRQ_NUM        PORTC_IRQn

#define BOARD_I2C_GPIO_SCL              GPIO_MAKE_PIN(GPIOB_IDX, 2)
#define BOARD_I2C_GPIO_SDA              GPIO_MAKE_PIN(GPIOB_IDX, 3)

#define HWADC_INSTANCE               1
#define ADC_IRQ_N                    ADC1_IRQn

/* The instances of peripherals used for dac_adc_demo */
#define BOARD_DAC_DEMO_DAC_INSTANCE     0U
#define BOARD_DAC_DEMO_ADC_INSTANCE     0U
#define BOARD_DAC_DEMO_ADC_CHANNEL      8U

/* The i2c instance used for i2c DAC demo */
#define BOARD_DAC_I2C_INSTANCE          0

/* The i2c instance used for i2c connection by default */
#define BOARD_I2C_INSTANCE              0

/* The dspi instance used for dspi example */
#define BOARD_DSPI_INSTANCE             0
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

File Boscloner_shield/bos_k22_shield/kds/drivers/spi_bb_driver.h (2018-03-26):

/*
 * spi_driver.h
 *
 *  Created on: Dec 15, 2015
 *      Author: MJ
 */

#ifndef SOURCES_SPI_DRIVER_H_
#define SOURCES_SPI_DRIVER_H_


#define PIN_C_D_LOC 6
#define PIN_C_D_HIGH  		(GPIOC_PSOR|= 1<<PIN_C_D_LOC)
#define PIN_C_D_LOW 		(GPIOC_PCOR|= 1<<PIN_C_D_LOC)
#define PIN_C_D_TOGGLE 		(GPIOC_PTOR|= 1<<PIN_C_D_LOC)

#define PIN_RST_LOC 4
#define PIN_RST_HIGH  		(GPIOC_PSOR|= 1<<PIN_RST_LOC)
#define PIN_RST_LOW 		(GPIOC_PCOR|= 1<<PIN_RST_LOC)
#define PIN_RST_TOGGLE 		(GPIOC_PTOR|= 1<<PIN_RST_LOC)


#define PIN_SCK_LOC 1
#define PIN_SCK_HIGH  		(GPIOD_PSOR|= 1<<PIN_SCK_LOC)
#define PIN_SCK_LOW 		(GPIOD_PCOR|= 1<<PIN_SCK_LOC)
#define PIN_SCK_TOGGLE 		(GPIOD_PTOR|= 1<<PIN_SCK_LOC)

#define PIN_MOSI_LOC 2
#define PIN_MOSI_HIGH  		(GPIOD_PSOR|= 1<<PIN_MOSI_LOC)
#define PIN_MOSI_LOW 		(GPIOD_PCOR|= 1<<PIN_MOSI_LOC)
#define PIN_MOSI_TOGGLE 	(GPIOD_PTOR|= 1<<PIN_MOSI_LOC)


#define PIN_CS_LOC 0
#define PIN_CS_HIGH  		(GPIOC_PSOR|= 1<<PIN_CS_LOC)
#define PIN_CS_LOW 			(GPIOC_PCOR|= 1<<PIN_CS_LOC)
#define PIN_CS_TOGGLE 		(GPIOC_PTOR|= 1<<PIN_CS_LOC)


void spi_bb_init(void);
void testIO(void);


#endif /* SOURCES_SPI_DRIVER_H_ */

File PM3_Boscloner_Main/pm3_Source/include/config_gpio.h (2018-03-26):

//-----------------------------------------------------------------------------
// This code is licensed to you under the terms of the GNU GPL, version 2 or,
// at your option, any later version. See the LICENSE.txt file for the text of
// the license.
//-----------------------------------------------------------------------------
// GPIO pin mapping for the Proxmark3
//-----------------------------------------------------------------------------

#ifndef __CONFIG_GPIO_H
#define __CONFIG_GPIO_H

#define GPIO_LED_A			AT91C_PIO_PA0
#define GPIO_PA1			AT91C_PIO_PA1
#define GPIO_LED_D			AT91C_PIO_PA2
#define GPIO_NVDD_ON		AT91C_PIO_PA3
#define GPIO_FPGA_NINIT		AT91C_PIO_PA4
#define GPIO_PA5			AT91C_PIO_PA5
#define GPIO_PCK0			AT91C_PA6_PCK0
#define GPIO_LRST			AT91C_PIO_PA7
#define GPIO_LED_B			AT91C_PIO_PA8
#define GPIO_LED_C			AT91C_PIO_PA9
#define GPIO_NCS2			AT91C_PA10_NPCS2
#define GPIO_NCS0			AT91C_PA11_NPCS0
#define GPIO_MISO			AT91C_PA12_MISO
#define GPIO_MOSI			AT91C_PA13_MOSI
#define GPIO_SPCK			AT91C_PA14_SPCK
#define GPIO_SSC_FRAME		AT91C_PA15_TF
#define GPIO_SSC_CLK		AT91C_PA16_TK
#define GPIO_SSC_DOUT		AT91C_PA17_TD
#define GPIO_SSC_DIN		AT91C_PA18_RD
#define GPIO_MUXSEL_HIPKD	AT91C_PIO_PA19
#define GPIO_MUXSEL_LOPKD	AT91C_PIO_PA20
#define GPIO_MUXSEL_HIRAW	AT91C_PIO_PA21
#define GPIO_MUXSEL_LORAW	AT91C_PIO_PA22
#define GPIO_BUTTON			AT91C_PIO_PA23
#define GPIO_USB_PU			AT91C_PIO_PA24
#define GPIO_RELAY			AT91C_PIO_PA25
#define GPIO_FPGA_ON		AT91C_PIO_PA26
#define GPIO_FPGA_DONE		AT91C_PIO_PA27
#define GPIO_FPGA_NPROGRAM	AT91C_PIO_PA28
#define GPIO_FPGA_CCLK		AT91C_PIO_PA29
#define GPIO_FPGA_DIN		AT91C_PIO_PA30
#define GPIO_FPGA_DOUT		AT91C_PIO_PA31

#endif
